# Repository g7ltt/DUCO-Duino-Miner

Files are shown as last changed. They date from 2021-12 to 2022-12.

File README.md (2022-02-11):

# DUCO/Duino-Miner

Here you will find designs for DUCO/DuinoCoin mining rigs based on various microcontrollers. All drawings are in Eagle format.

# 5DN
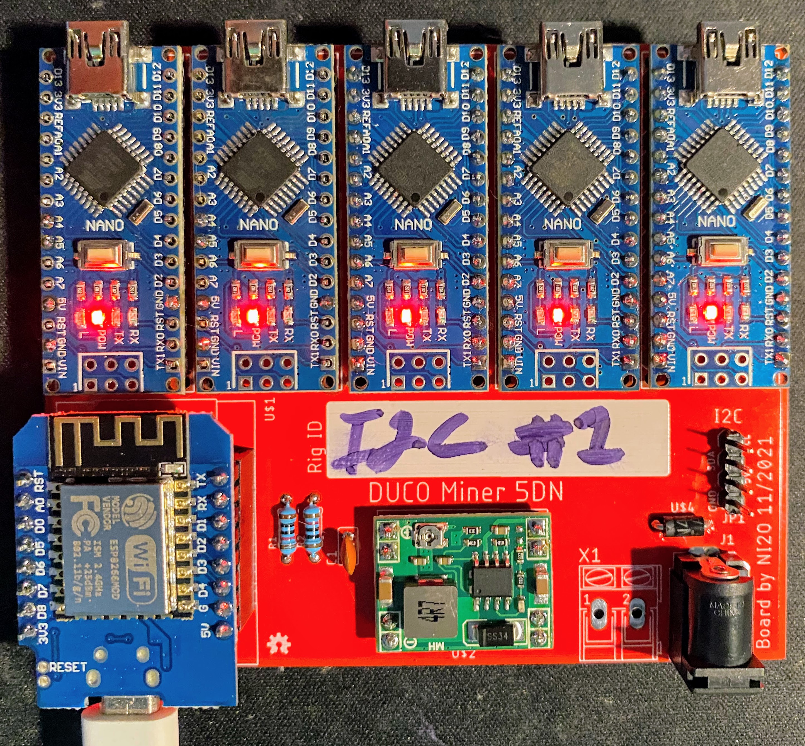
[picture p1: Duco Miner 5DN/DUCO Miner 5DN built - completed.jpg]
DUCO-Miner 5DN

Uses a Wemos D1 and 5 arduino Nano's. I2C communications between the Wemos and the Nano's with the Wemos handling the network connection via WiFi. An LCD can be added for diagnostic output adn the boards can be "stacked" via the I2C bus. When stacked only a single Wemos is required. Uses code by Ricuan and JK Rolling

# 16-01
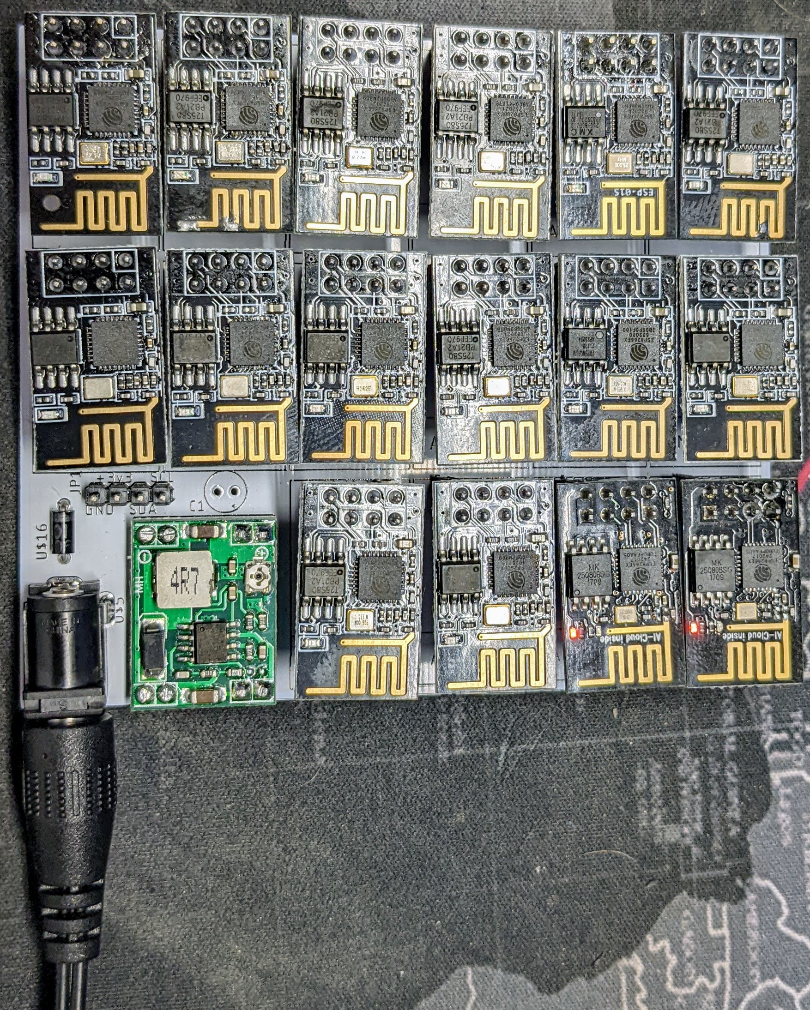
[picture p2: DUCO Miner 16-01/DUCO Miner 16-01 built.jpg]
DUCO-Miner 16-01

Uses 16 ESP-01 modules in one of 2 configurations; I2C Master/Slave mode or WiFi only. In I2C mode uses 1 of the ESP-01's as a Master talking to 15 slaves. wiFi only uses the WiFi radio on all the devices.

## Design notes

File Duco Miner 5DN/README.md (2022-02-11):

# Duco Miner 5DN
Arduino Nano (ATMEGA328) and Wemos D1 (ESP8266) based DUCO/Duino Coin miner. Uses a Wemos D1 as an I2C master controlling the 5 Nano I2C slaves. WiFi/Network handled by the Wemos microcontroller.
DUCO-Miner 5DN

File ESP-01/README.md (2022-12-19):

# Duco Miner ESP-01 8DN
ESP-01 (ESP8266) based DUCO/Duino Coin miner. Uses up to 8 ESP-01 modules. WiFi/Network handled by the module itself.
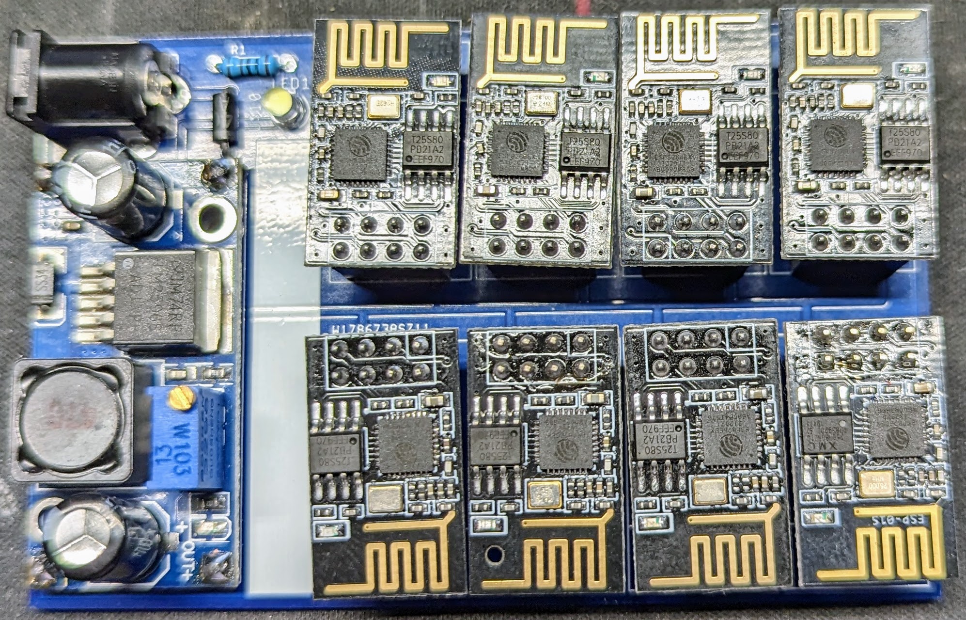
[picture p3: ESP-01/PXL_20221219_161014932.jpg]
DUCO-Miner ESP-01 8DN


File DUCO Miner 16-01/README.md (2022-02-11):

# DUCO Miner 16-01

ESP-01 (ESP8266) based DUCO/Duino Coin miner. Uses a gang of ESP-01 Microcontrollers.
DUCO Miner 5DN

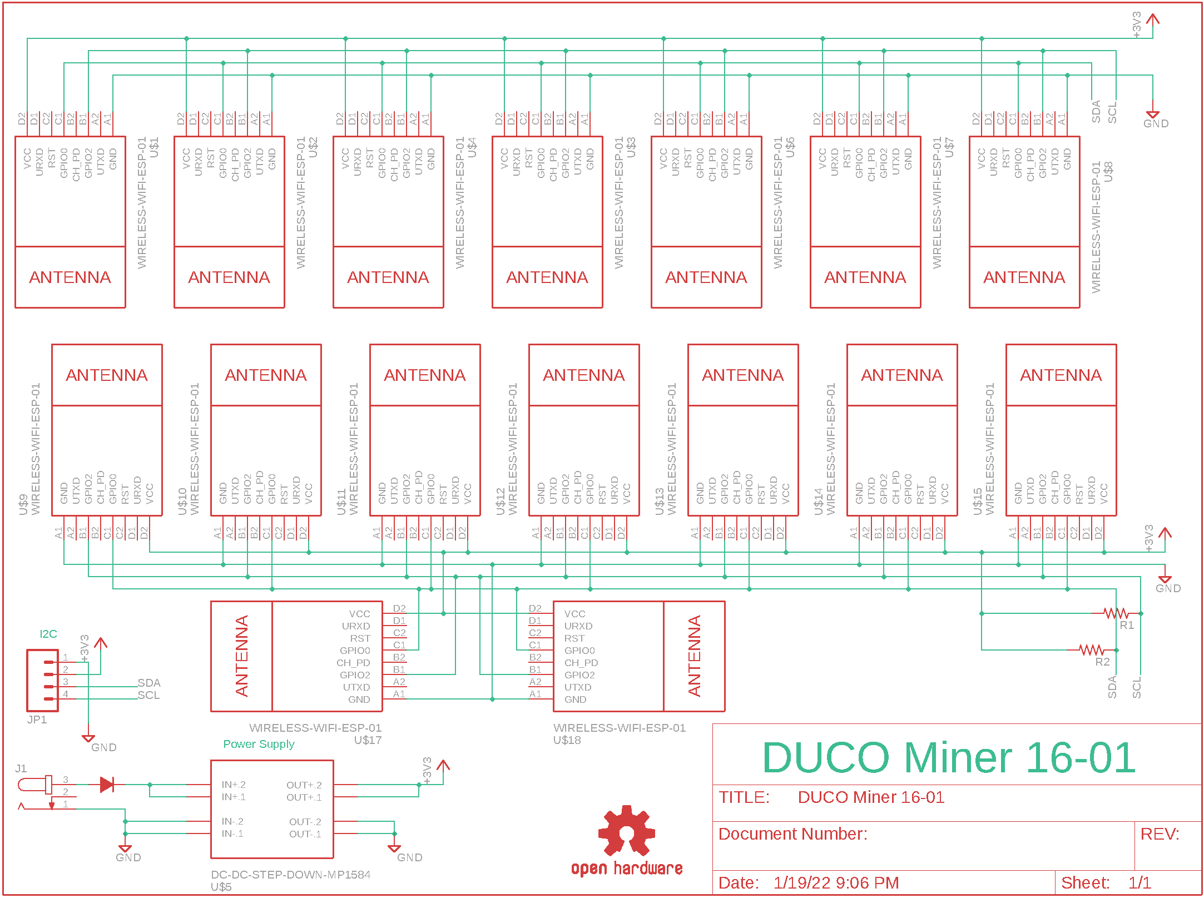
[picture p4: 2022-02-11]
DUCO Miner 16-01/DUCO Miner 16-01 schematic.png

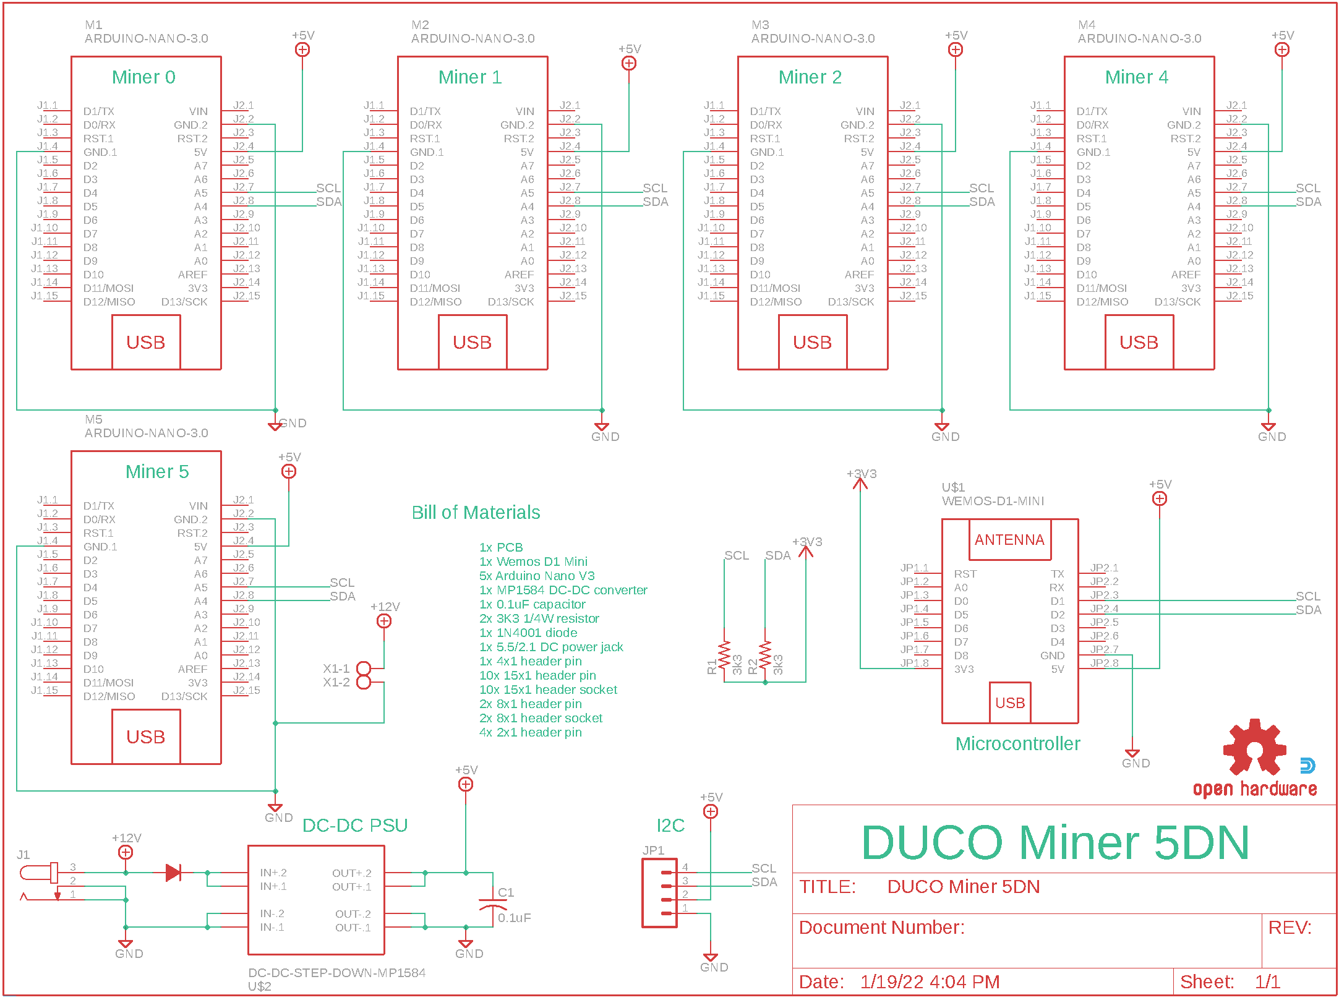
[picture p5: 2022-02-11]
Duco Miner 5DN/DUCO Miner 5DN schematic.png

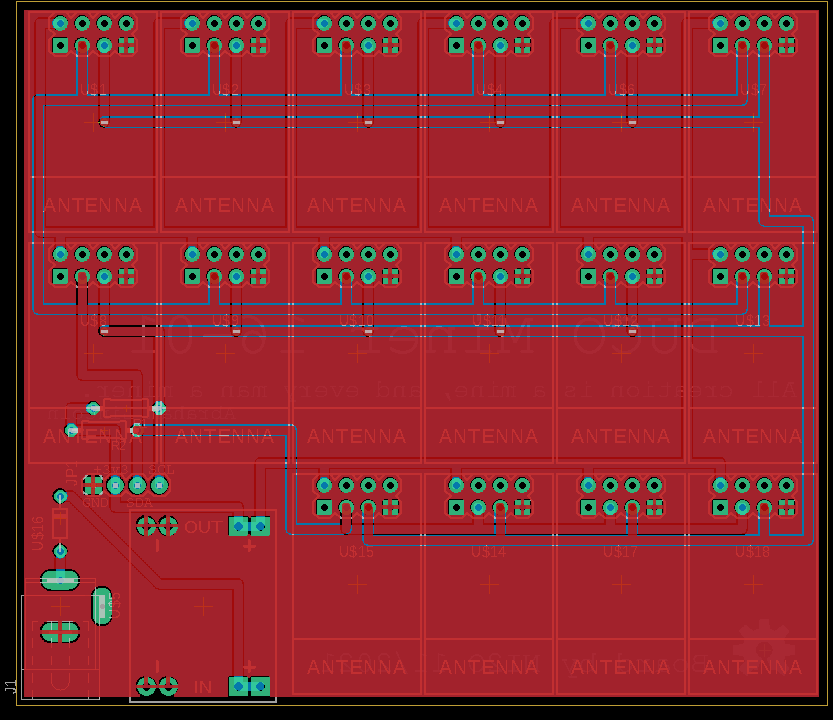
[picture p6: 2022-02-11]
DUCO Miner 16-01/DUCO Miner 16-01.png

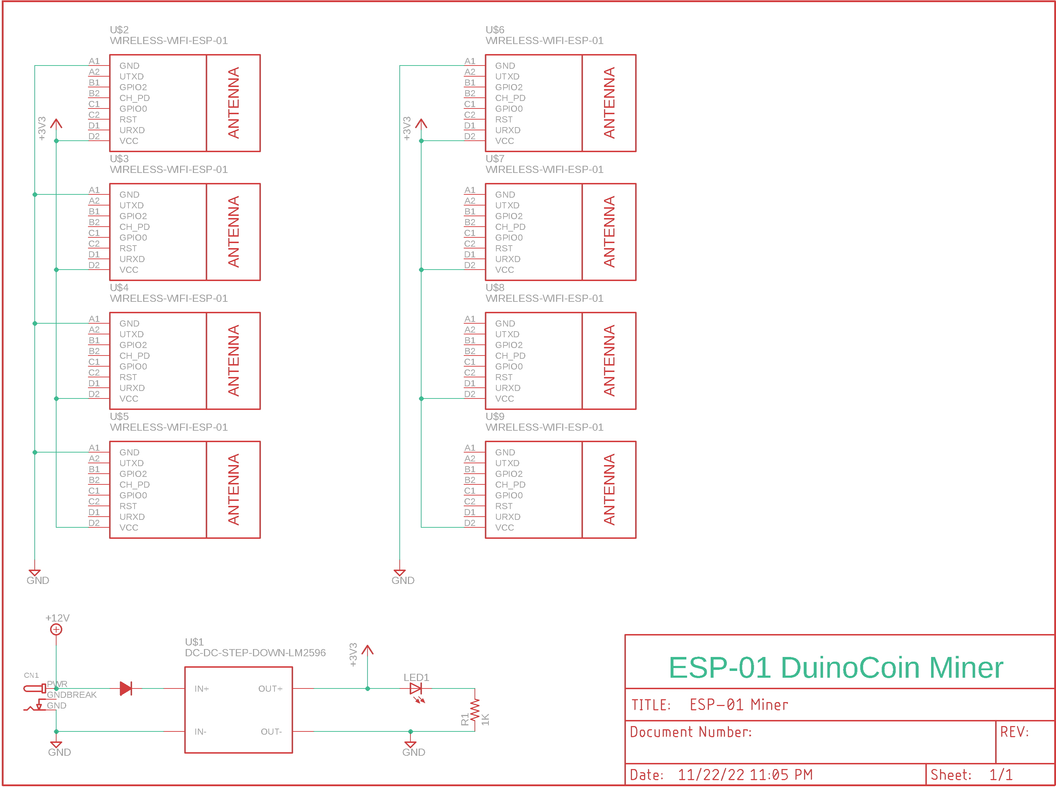
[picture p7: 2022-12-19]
ESP-01/circuit_diagram.png

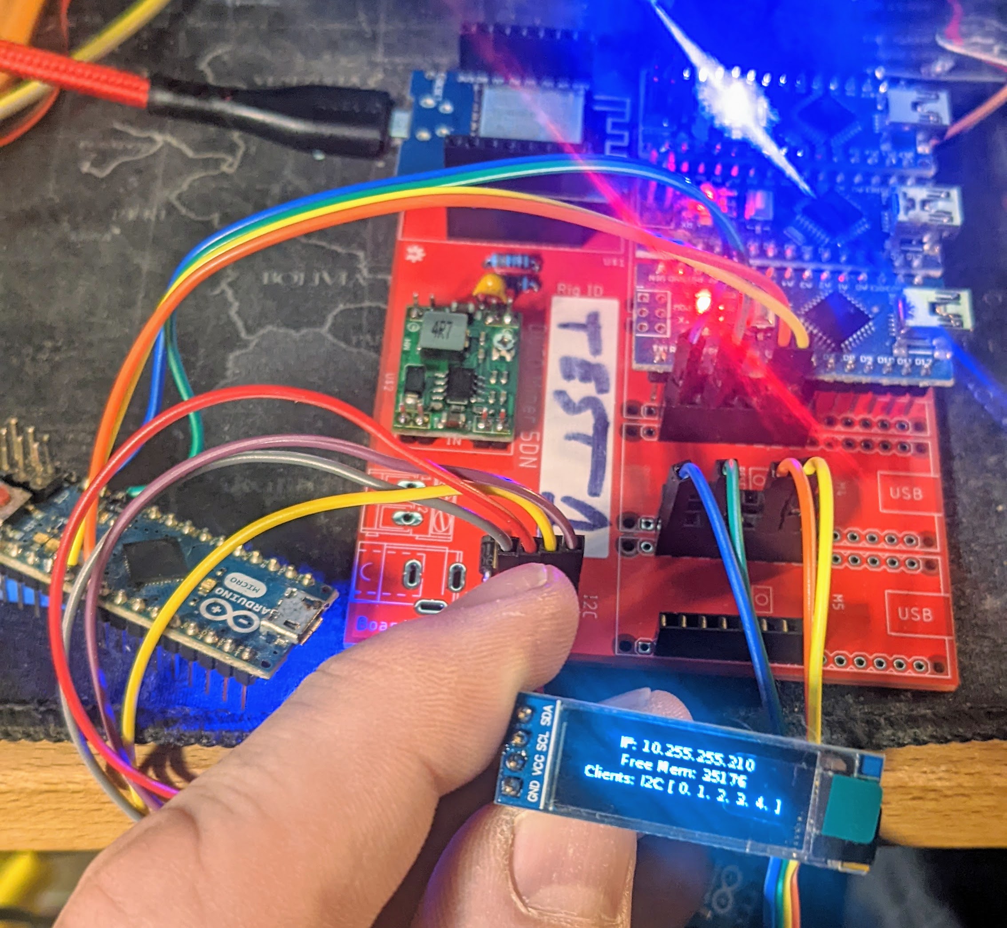
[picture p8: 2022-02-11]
Duco Miner 5DN/DUCO Miner 5DN built - LCD.jpg

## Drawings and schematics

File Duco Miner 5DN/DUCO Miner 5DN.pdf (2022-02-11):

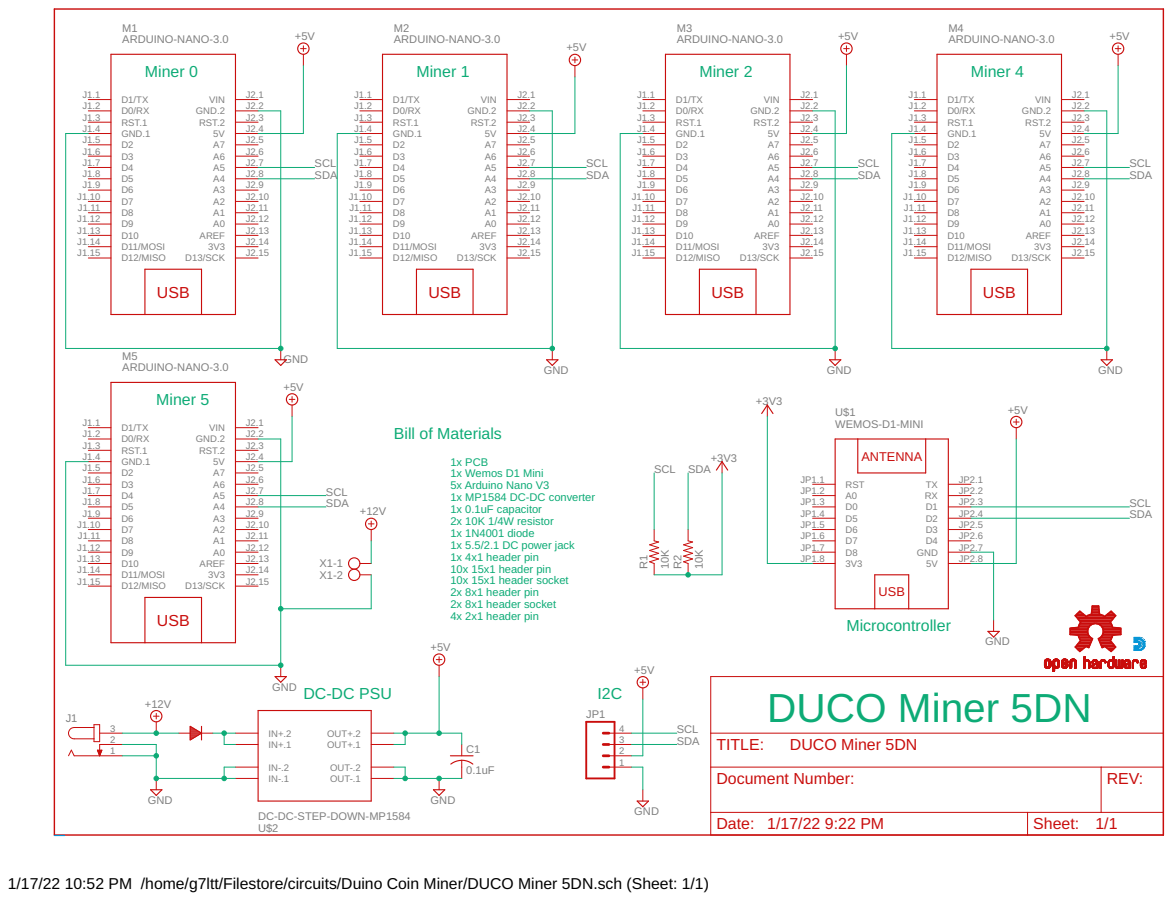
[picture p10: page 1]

1x PCB
1x Wemos D1 Mini
5x Arduino Nano V3
1x MP1584 DC-DC converter 1x 0.1uF capacitor 2x 10K 1/4W resistor 1x 1N4001 diode

Document Number: | REV:

DC-DC-STEP-DOWN-MP1584

Date: 1/17/22 9:22 PM | Sheet: 1/1

1/17/22 10:52 PM /home/g7ltt/Filestore/circuits/Duino Coin Miner/DUCO Miner 5DN.sch (Sheet: 1/1)

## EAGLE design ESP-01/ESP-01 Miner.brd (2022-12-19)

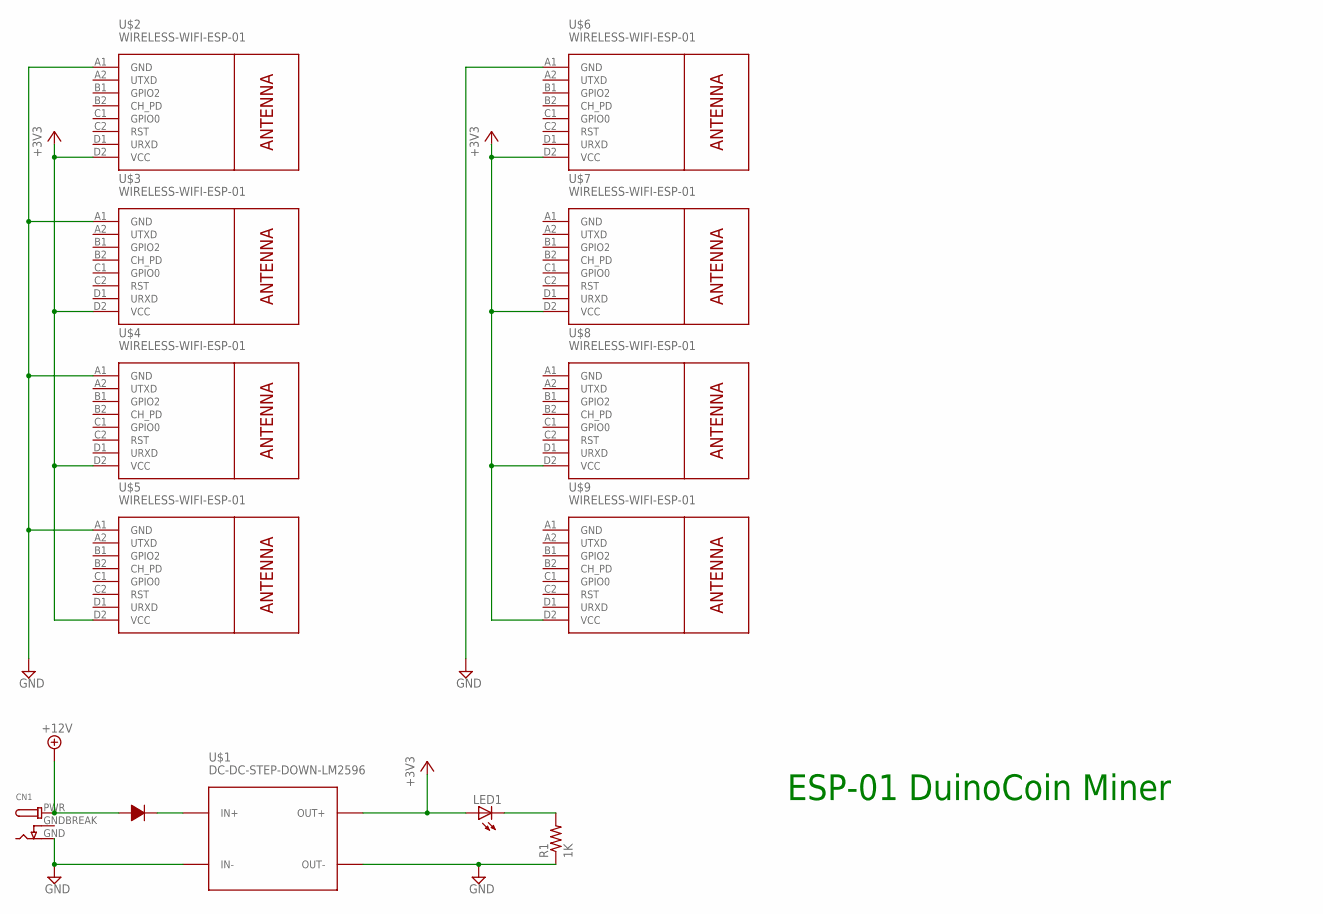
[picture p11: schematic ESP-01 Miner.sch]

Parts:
CN1: DCBARRELPTH; DCJACK_2MM_PTH
LED1: LED3MM
R1: 1K; 0204/7
U$1: DC-DC-STEP-DOWN-LM2596
U$2, U$3, U$4, U$5, U$6, U$7, U$8, U$9: WIRELESS-WIFI-ESP-01
U$10: 1N4001; DIODE-12.70

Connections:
+3V3: LED1.A, U$1.OUT+, U$2.D2 (VCC), U$3.D2 (VCC), U$4.D2 (VCC), U$5.D2 (VCC), U$6.D2 (VCC), U$7.D2 (VCC), U$8.D2 (VCC), U$9.D2 (VCC)
+12V: CN1.PWR, U$10.P$1
GND: CN1.GND, R1.1, U$1.IN-, U$1.OUT-, U$2.A1 (GND), U$3.A1 (GND), U$4.A1 (GND), U$5.A1 (GND), U$6.A1 (GND), U$7.A1 (GND), U$8.A1 (GND), U$9.A1 (GND)
GNDBREAK: CN1.GNDBREAK
unnamed: U$1.IN+, U$10.P$2
unnamed: LED1.K (C), R1.2

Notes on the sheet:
ESP-01 DuinoCoin Miner

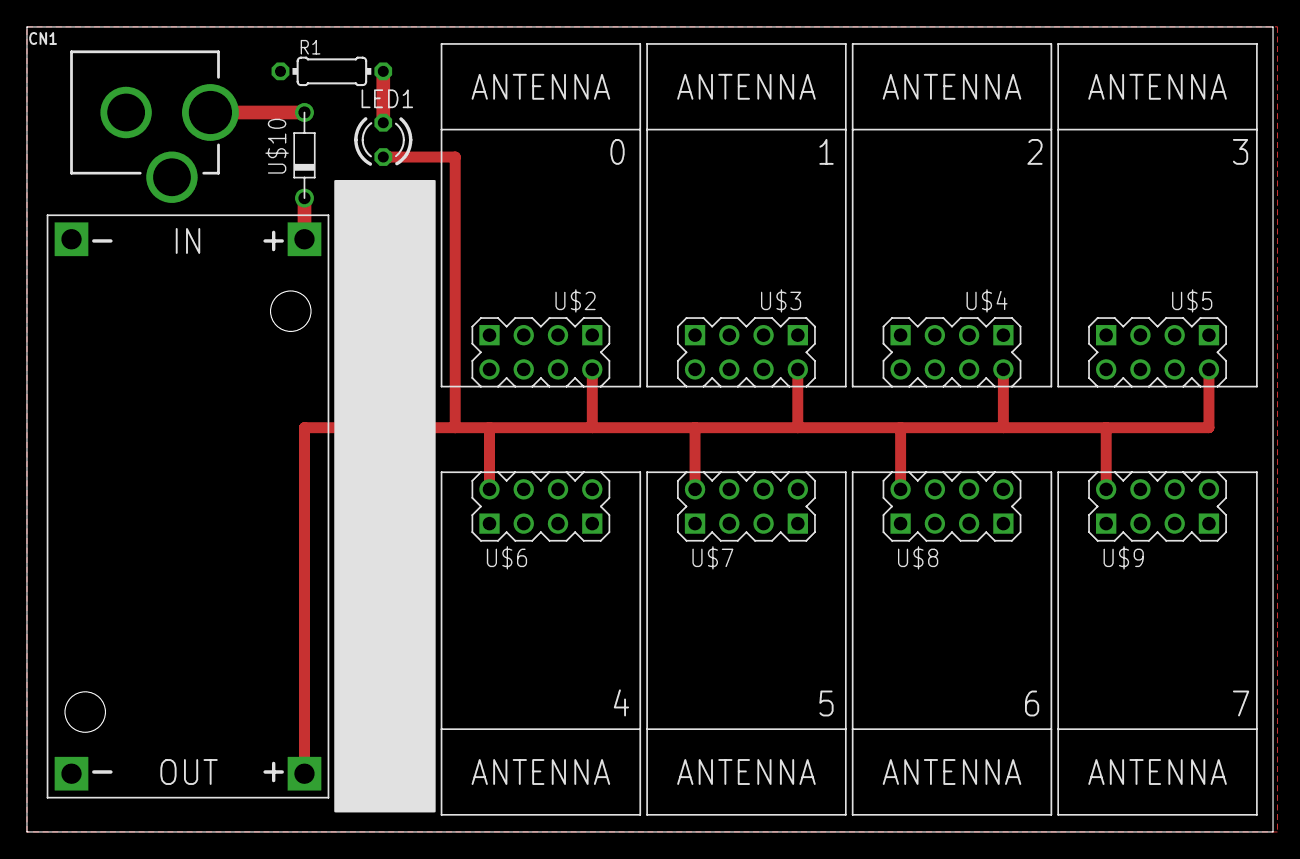
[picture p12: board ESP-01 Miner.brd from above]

Board: 2 copper layers, 92.4 x 59.7 mm, 13 parts (0 on the bottom side), 5 nets.

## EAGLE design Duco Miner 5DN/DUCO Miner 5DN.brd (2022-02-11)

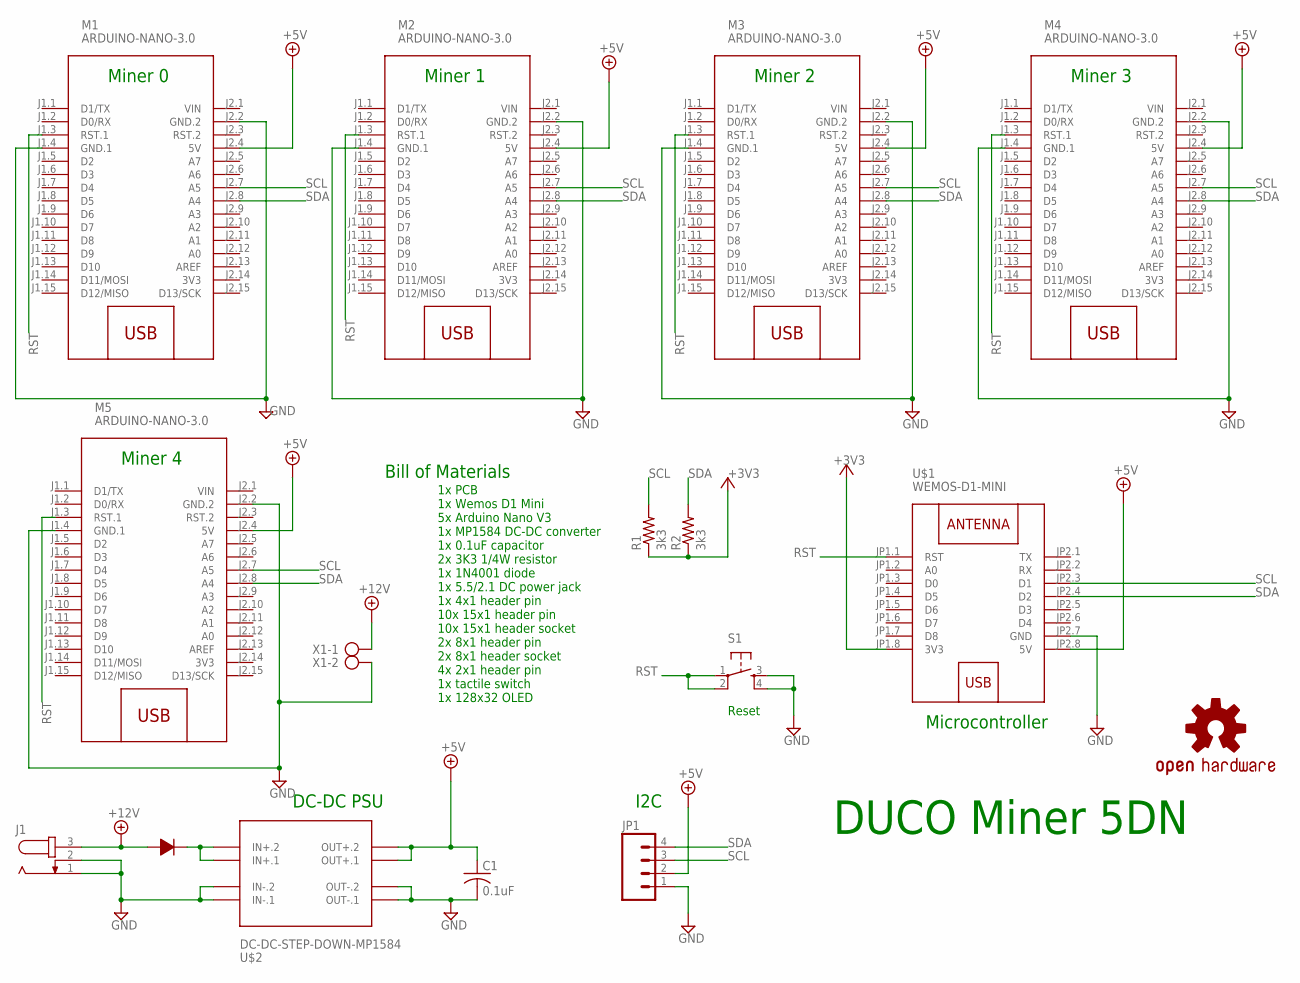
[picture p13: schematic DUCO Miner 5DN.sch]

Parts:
C1: 0.1uF; C025-025X050
J1: JACK-PLUG1; SPC4078
JP1: M04PTH; 1X04
LOGO1: OSHW-LOGOS; OSHW-LOGO-S
M1, M2, M3, M4, M5: ARDUINO-NANO-3.0
R1, R2: 3k3; 0204/7
S1: TAC_SWITCHPTH; TACTILE-PTH
U$1: WEMOS-D1-MINI
U$2: DC-DC-STEP-DOWN-MP1584
U$4: 1N4001; DIODE-12.70
X1: AK300/2

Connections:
3V3: M1.J2.14 (3V3), M2.J2.14 (3V3), M3.J2.14 (3V3), M4.J2.14 (3V3), M5.J2.14 (3V3)
+3V3: R1.1, R2.1, U$1.JP1.8 (3V3)
+5V: C1.1, JP1.2, M1.J2.4 (5V), M2.J2.4 (5V), M3.J2.4 (5V), M4.J2.4 (5V), M5.J2.4 (5V), U$1.JP2.8 (5V), U$2.OUT+.1, U$2.OUT+.2
+12V: J1.3, U$4.P$1, X1.1
GND: C1.2, J1.1, J1.2, JP1.1, M1.J1.4 (GND.1), M1.J2.2 (GND.2), M2.J1.4 (GND.1), M2.J2.2 (GND.2), M3.J1.4 (GND.1), M3.J2.2 (GND.2), M4.J1.4 (GND.1), M4.J2.2 (GND.2), M5.J1.4 (GND.1), M5.J2.2 (GND.2), S1.3, S1.4, U$1.JP2.7 (GND), U$2.IN-.1, U$2.IN-.2, U$2.OUT-.1, U$2.OUT-.2, X1.2
unnamed: U$2.IN+.1, U$2.IN+.2, U$4.P$2
RST: M1.J1.3 (RST.1), M2.J1.3 (RST.1), M3.J1.3 (RST.1), M4.J1.3 (RST.1), M5.J1.3 (RST.1), S1.1, S1.2, U$1.JP1.1 (RST)
SCL: JP1.3, M1.J2.7 (A5), M2.J2.7 (A5), M3.J2.7 (A5), M4.J2.7 (A5), M5.J2.7 (A5), R1.2, U$1.JP2.3 (D1)
SDA: JP1.4, M1.J2.8 (A4), M2.J2.8 (A4), M3.J2.8 (A4), M4.J2.8 (A4), M5.J2.8 (A4), R2.2, U$1.JP2.4 (D2)
VIN: M1.J2.1 (VIN), M2.J2.1 (VIN), M3.J2.1 (VIN), M4.J2.1 (VIN), M5.J2.1 (VIN)

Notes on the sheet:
Miner 0
Miner 1
Miner 2
Miner 4
Miner 3
DUCO Miner 5DN
Microcontroller
DC-DC PSU
I2C
Bill of Materials
1x PCB 1x Wemos D1 Mini 5x Arduino Nano V3 1x MP1584 DC-DC converter 1x 0.1uF capacitor 2x 3K3 1/4W resistor 1x 1N4001 diode 1x 5.5/2.1 DC power jack 1x 4x1 header pin 10x 15x1 header pin 10x 15x1 header socket 2x 8x1 header pin 2x 8x1 header socket 4x 2x1 header pin 1x tactile switch 1x 128x32 OLED
Reset

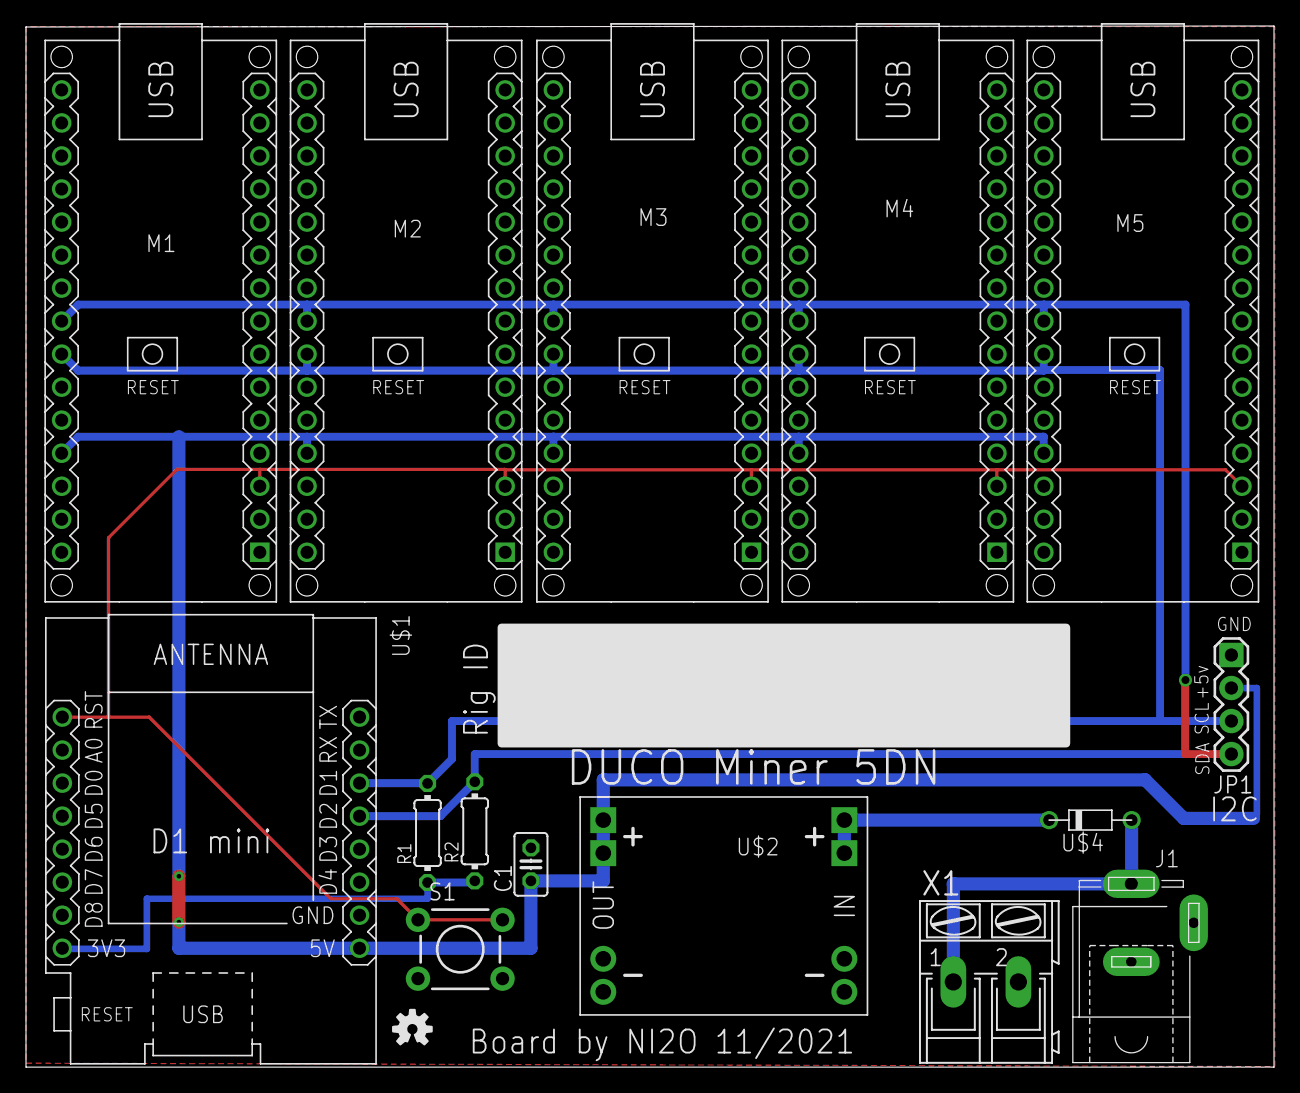
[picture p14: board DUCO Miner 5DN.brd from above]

Board: 2 copper layers, 96.0 x 80.1 mm, 16 parts (0 on the bottom side), 10 nets.

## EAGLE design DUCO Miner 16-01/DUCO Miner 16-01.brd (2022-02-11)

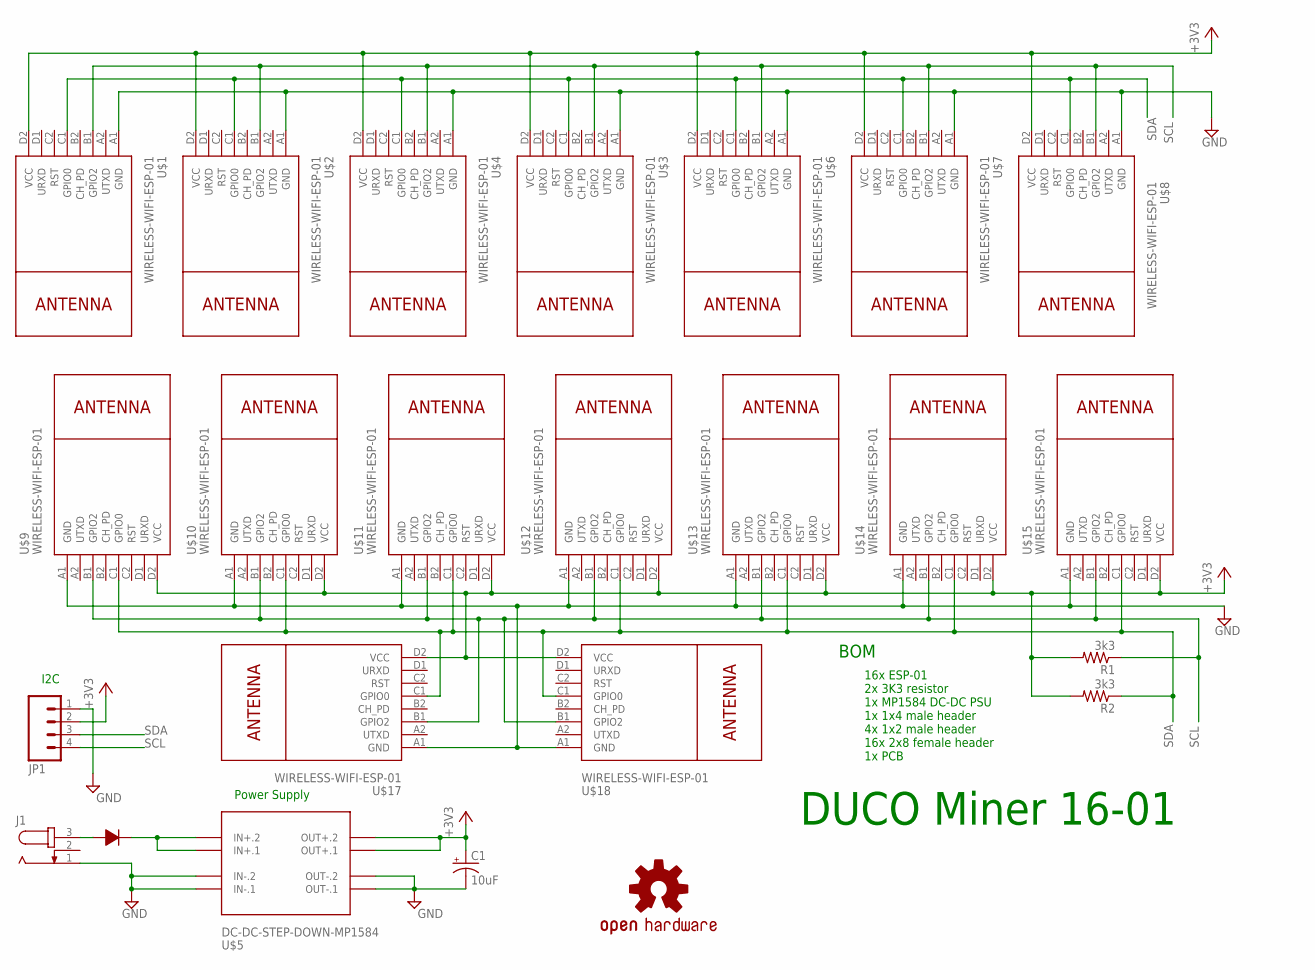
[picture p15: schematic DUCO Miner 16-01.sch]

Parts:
C1: 10uF; E2-5
J1: JACK-PLUG0; SPC4077
JP1: M04PTH; 1X04
LOGO1: OSHW-LOGOL; OSHW-LOGO-L
R1, R2: 3k3; 0204/7
U$1, U$2, U$3, U$4, U$6, U$7, U$8, U$9, U$10, U$11, U$12, U$13, U$14, U$15, U$17, U$18: WIRELESS-WIFI-ESP-01
U$5: DC-DC-STEP-DOWN-MP1584
U$16: 1N4001; DIODE-12.70

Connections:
+3V3: C1.+, JP1.2, R1.2, R2.2, U$1.D2 (VCC), U$2.D2 (VCC), U$3.D2 (VCC), U$4.D2 (VCC), U$5.OUT+.1, U$5.OUT+.2, U$6.D2 (VCC), U$7.D2 (VCC), U$8.D2 (VCC), U$9.D2 (VCC), U$10.D2 (VCC), U$11.D2 (VCC), U$12.D2 (VCC), U$13.D2 (VCC), U$14.D2 (VCC), U$15.D2 (VCC), U$17.D2 (VCC), U$18.D2 (VCC)
GND: C1.-, J1.1, JP1.1, U$1.A1 (GND), U$2.A1 (GND), U$3.A1 (GND), U$4.A1 (GND), U$5.IN-.1, U$5.IN-.2, U$5.OUT-.1, U$5.OUT-.2, U$6.A1 (GND), U$7.A1 (GND), U$8.A1 (GND), U$9.A1 (GND), U$10.A1 (GND), U$11.A1 (GND), U$12.A1 (GND), U$13.A1 (GND), U$14.A1 (GND), U$15.A1 (GND), U$17.A1 (GND), U$18.A1 (GND)
unnamed: J1.3, U$16.P$1
unnamed: U$5.IN+.1, U$5.IN+.2, U$16.P$2
SCL: JP1.4, R1.1, U$1.B1 (GPIO2), U$2.B1 (GPIO2), U$3.B1 (GPIO2), U$4.B1 (GPIO2), U$6.B1 (GPIO2), U$7.B1 (GPIO2), U$8.B1 (GPIO2), U$9.B1 (GPIO2), U$10.B1 (GPIO2), U$11.B1 (GPIO2), U$12.B1 (GPIO2), U$13.B1 (GPIO2), U$14.B1 (GPIO2), U$15.B1 (GPIO2), U$17.B1 (GPIO2), U$18.B1 (GPIO2)
SDA: JP1.3, R2.1, U$1.C1 (GPIO0), U$2.C1 (GPIO0), U$3.C1 (GPIO0), U$4.C1 (GPIO0), U$6.C1 (GPIO0), U$7.C1 (GPIO0), U$8.C1 (GPIO0), U$9.C1 (GPIO0), U$10.C1 (GPIO0), U$11.C1 (GPIO0), U$12.C1 (GPIO0), U$13.C1 (GPIO0), U$14.C1 (GPIO0), U$15.C1 (GPIO0), U$17.C1 (GPIO0), U$18.C1 (GPIO0)

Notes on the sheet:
DUCO Miner 16-01
Power Supply
I2C
BOM
16x ESP-01 2x 3K3 resistor 1x MP1584 DC-DC PSU 1x 1x4 male header 4x 1x2 male header 16x 2x8 female header 1x PCB

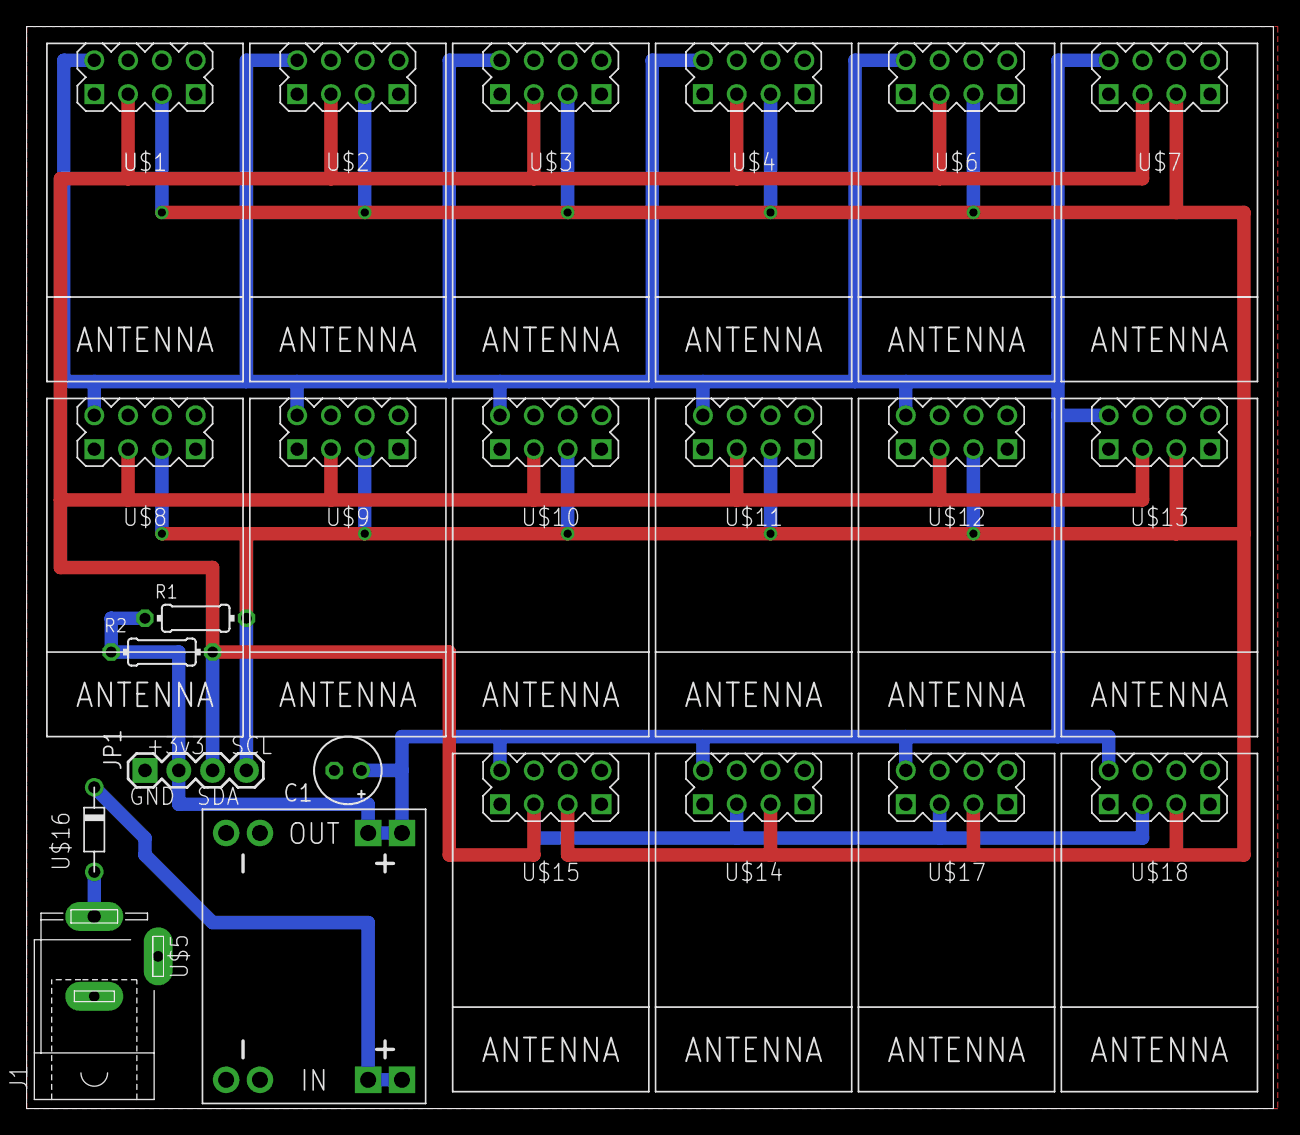
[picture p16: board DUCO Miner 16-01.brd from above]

Board: 2 copper layers, 93.7 x 81.3 mm, 24 parts (1 on the bottom side), 6 nets.

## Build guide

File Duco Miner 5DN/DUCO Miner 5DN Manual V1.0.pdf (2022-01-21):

# DUCO Miner 5DN

# Installation notes

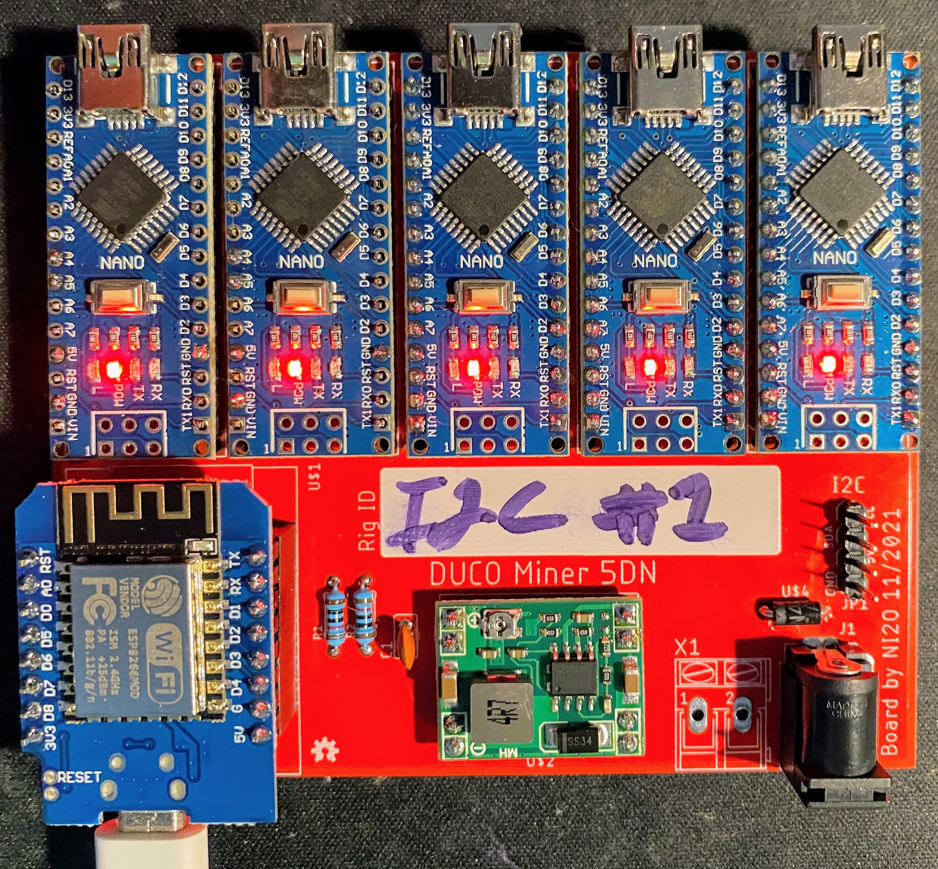
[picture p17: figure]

# January 2021 V1.0

Thank you for purchasing the DUCO Miner 5DN.

The DUCO Miner 5DN is comprised of the following components;

- Up to 5 Arduino Nano V3 micro controller boards,
- 1x Wemos D1 micro controller board with WiFi
•
- 12V power supply

The Miner is an standalone WiFi/I2C based miner. It will not identify itself to desktop software as a USB or similar mining tool.

Power for the Miner can be supplied either by a external 9-18VDC power supply or by attaching a USB cable to the Wemos micro controller.

Your DUCO Miner 5DN will mine Duino Coin at a rate of around 220H/s per dedicated micro processor. Before using your Miner you will be required to program the Wemos D1 with the latest sketch including your WiFi and DUCO network credentials.

Upon application of power your Miner will attempt to access your WiFi and then download work units for the Nano boards to work on. It will return the results of this work when complete and start over again.

Firmware updates can be found here

- https://github.com/JK-Rolling/DuinoCoinI2C

From time to time it may be necessary to update the firmware in the Arduino Nano micro controllers. The above link will also provide that firmware. Should any of the micro controllers fail during the service lifetime of your Miner simply remove it and install another with the firmware from the link above.

Supplied on the pre-built Miners is a 12v DC-DC power supply. It has already been set to output 4.8vDC to the attached micro controllers. If you are building this from a kit then it will be required to set the voltage of the DC-DC power supply BEFORE installing any micro controllers. Install the power supply and its support components and then insert the probes of a voltage meter into the “VTEST” holes on the PCB. Set the required voltage by adjusting the small potentiometer on the power supply unit until the output is around 4.8vDC

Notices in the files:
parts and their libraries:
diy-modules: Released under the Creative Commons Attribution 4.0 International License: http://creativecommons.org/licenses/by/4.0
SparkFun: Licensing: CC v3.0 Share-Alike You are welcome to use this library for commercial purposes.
